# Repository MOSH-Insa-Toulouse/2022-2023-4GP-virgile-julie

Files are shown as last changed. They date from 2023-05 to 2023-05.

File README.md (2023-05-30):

# 2022-2023-4GP-virgile-julie
Projet 4GP du capteur au banc de test en open source hardware
---
## Sommaire
  - [1) Livrables](#1-livrables)
  - [2) Description](#2-description)
  - [3) Shield PCB](#3-shield-pcb)
  - [4) Arduino](#4-arduino)
  - [5) Application Android APK](#5-application-android-apk)
  - [6) Banc de test et mesures](#6-banc-de-test-et-mesures)
  - [7) Datasheet](#7-datasheet)
  - [8) Limites et perspectives](#8-Limites-et-perspectives)
---
## 1) Livrables

Lors de notre projecteur, nous avons décidé de réaliser l'ensemble des options (headers) sur la schématique du shield: 
- capteur
- module bluetooth
- flex sensor
- écran OLED
- potentiomètre digital
 
 Pour se faire, nous avons du réaliser un cahier des charges adaptés:
 
-  Réalisation d'un Shield PCB sur KiCad
-  Réalisation d'un code Arduino permettant la mesure du capteur, ainsi que le réglage du potentiomètre, l'affichage sur un écran OLED, l'envoie des données par module Bluetooth
- Réalisation d'une Application android APK réalisée avec MIT APP INVENTOR
- Réalisation d'une Datasheet du capteur
---
## 2) Description

Dans ce projet, nous allons concevoir un capteur résistif fonctionnant sur la base d'un phénomène physique observé qui est l'effet tunnel. En faisant varier la distance séparant les particules du réseau( par des déformations en compression et en tension), la conductivité du graphite varie ainsi que sa résistivité.

Pour appliquer ce phènomène, la jauge de contrainte sera peu couteuse. Elle se présente sous la forme d’un U en papier, sur lequel on vient déposer du graphite à l’aide d’un crayon à papier ceci est très simple à réaliser et sa fabrication ne génère pas d’impact négatif sur l’environnement. A noter aussi que la réponse du capteur va dépendre du type de mine utilisée. 

Nous avons débuté notre projet par la fabrication de notre shield pour notre chaine de mesures. Ce dernier a été conçu a l'aide du logiciel KICAD  sur la base du amplificateur transimpédance simulation électrique du circuit associé au shield sur le logiciel LTSpice.

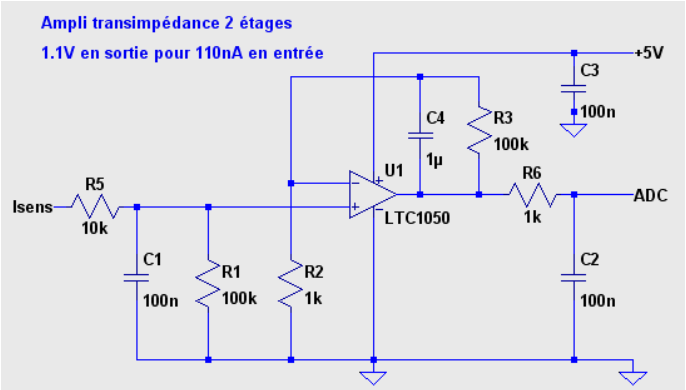
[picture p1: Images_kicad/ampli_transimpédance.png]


Pour exploiter le signal de sortie du capteur par un convertisseur analogique-numérique d’une carte Arduino, la sortie du capteur est reliée à un circuit amplificateur transimpédance. Ce circuit dispose de trois étages de filtrage : 
- Un filtre passe-bas R1C1 qui permet de filtrer les bruits en courants sur le signal d’entrée
- Un filtre passe bas R3C4 couplé à un amplificateur opérationnel LTC1050 permettant de filtrer la composante du bruit à 50 Hz provenant du réseau électrique
- Un filtre de sortie R5C2 qui coupe les bruits due à l’échantillonnage de l’ADC
On retrouve la valeur de résistance du capteur grâce à la formule suivante : 
R=(1+R3/R2)*R1*Vcc/Vadc-R1-R5

Par la suite, nous avons ensuite imprimé notre circuit PCB après validation de celle-ci, qui aura demande de multiples essais. 
Puis, nous avons réalisé le montage des composants sur la carte vierge avec le matériel ci-dessous.

Matériel nécessaire
* 1 carte Arduino Uno
* 2 Résistance de 100kΩ
* 1 Résistance de 1kΩ
* 1 Potentiomètre digital MCP-41050
* 2 Condensateurs 100nF
* 1 Condensateurs 1µF
* 1 AOP LTC1050
* 1 Écran OLED01
* 1 Module Bluetooth HC-05

Puis, nous avons codé avec l'usage d'une carte Arduino le code permettant la lecture des mesures du capteur ainsi que l'ajout sur le code des fonctions associés aux différentes options ajoutés soit l'écran OLED, le module Bluetooth et le potentiomètre digital.  
Ensuite, nous avons développé une application Android qui a pour but de recevoir des données via Bluetooth grâce le site MIT App Inventor.  
Et enfin, nous avons réalisé notre propre banc de test : nous avons effectué un test de rayon de courbure et un test de répétabilité avec deux types de crayons (2B, HB2).  

---
## 3) Shield PCB

### Réalisation de la Schématique de Shield
Cette partie se consacre à la réalisation et la fabrication du support éléctronique, soit le PCB de notre projet. Il a été réalisé sur le logiciel Kicad en se basant sur le template d'un arduino uno.

Pour se faire, nous avons conçu l'ensemble des symboles et empreintes associés aux options choisis précédements. Avec les empreintes, nous les avons connecté avec le reste du circuit existant afin d'obtenir notre shield.

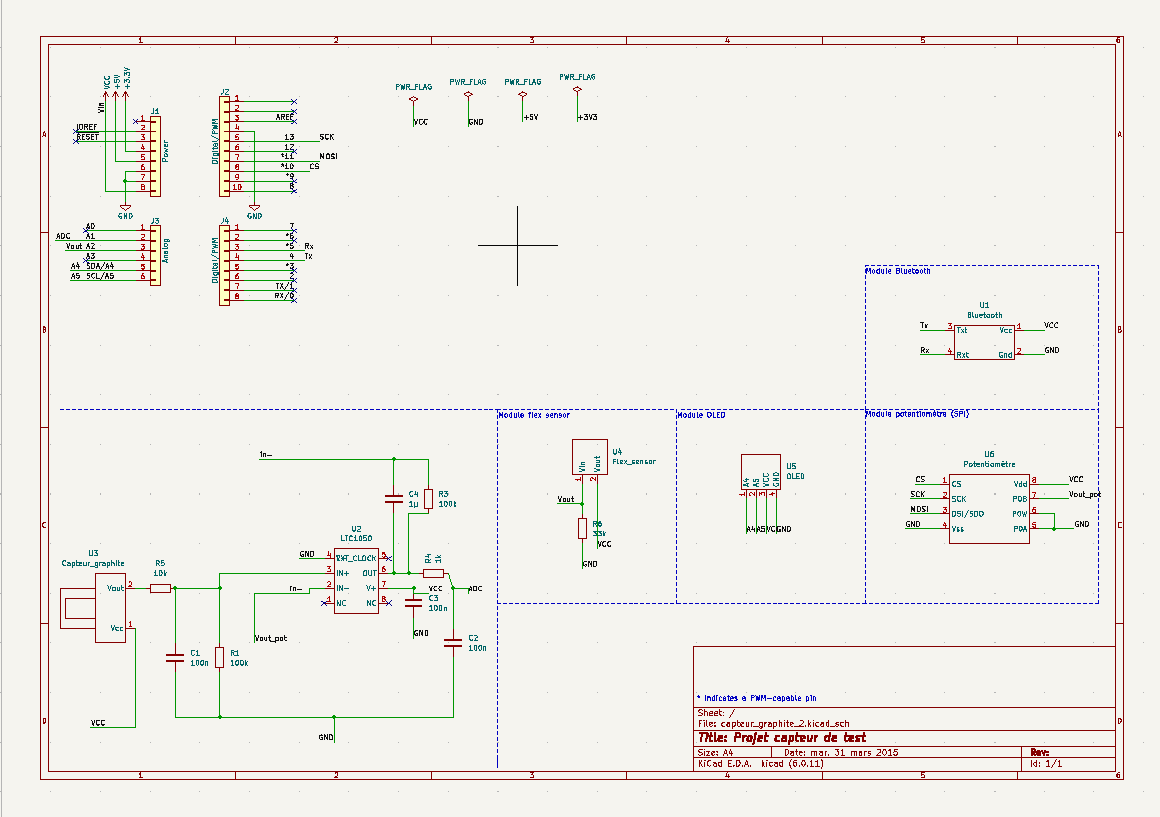
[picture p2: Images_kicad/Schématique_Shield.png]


### Réalisation de la Schématique du PCB
En se basant sur notre Shield, nous avons réalisé le routage de notre circuit en prenant soin de limiter les distances entre les composantes et leur pins associés. Cette étape fut très laboriseuse car le fait d'avoir une seule couche pour le PCB, nous obligeait de trouver des stratagèmes d'optimisation de place et de placement. Lorsque cette étape était fini, nous pouvons passer à la pose du plan de masse de notre circuit.

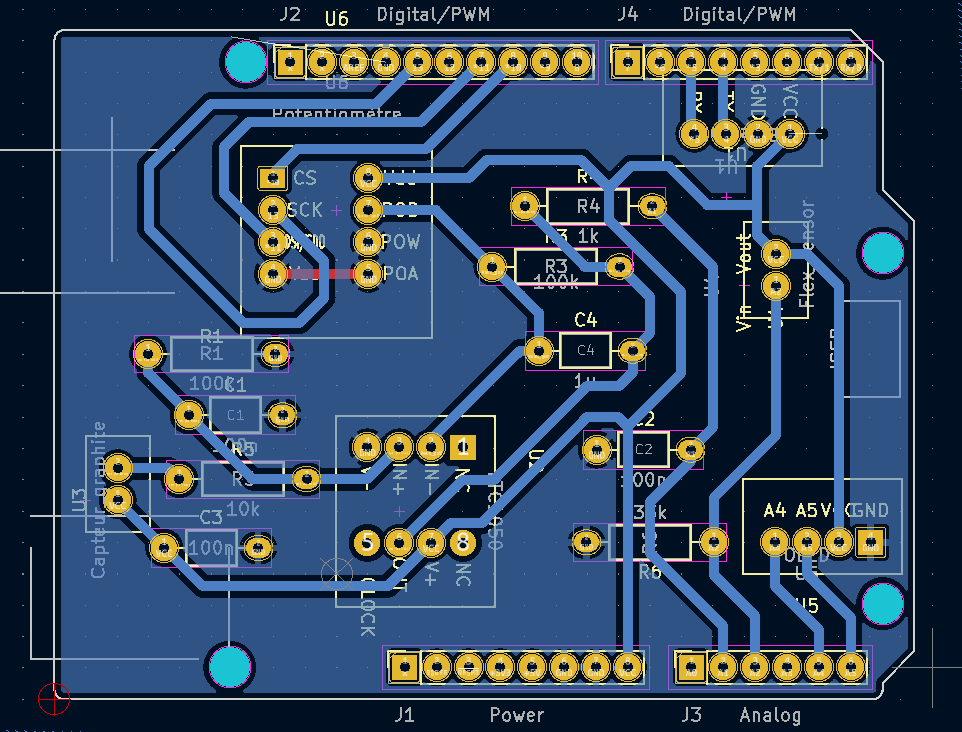
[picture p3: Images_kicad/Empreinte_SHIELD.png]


Comme nous pouvons le voir, le résultant possède néanmoins un fil supplémentaire, un fil rouge, qui sera ajouté lors de la fabrication du shield pour respecter le plan de masse. 

### Fabrication du PCB
Le PCB a été fabriqué à partir d'une plaquette d’époxy recouverte d’une fine couche de cuivre. 

Etapes de fabrication:

* Réaliser une insolation aux UVs de notre plaquette avec le calque de notre circuit (10 minutes)
* Retirer la partie de résine non isolée avec un révélateur
* Plonger notre plaquette dans un bain de percholorure de fer

### Assemblage des composantes
Lorsque le PCB a été fabriqué, il nous reste l'étape d'assemblage du shield. Pour se faire, il nous faut donc percer le PCB et souder les composants.
Pour ce qui est du perçage, dans les consignes, il était dit de prévoir deux tailles de trous sur le Kicad, soit un de diamètre 0,8mm pour les composants et headers et un de diamètre 1mm pour les broches de connexion de la carte Arduino Uno.

## 4) Arduino

## 5) Application Android APK
Nous avons développé une application android à l’aide du développeur MIT App Inventor. Couplée au module Bluetooth HC-05, cette application permet d’afficher en direct la résistance du capteur et l’évolution de la résistance en fonction du temps grâce à  un graphique déroulant.

appli_bluetooth

Voici le schéma block de notre application : 

schéma_block_appli_1

schéma_block_appli_2

Le graphique déroulant permet une analyse qualitative plus que quantitative car le graphique déroulant n’a pas d’échelle en ordonnée. 
Les limites de cette application sont : 
-	Si on lance l’application alors que la carte Arduino tournait déjà, il y a une erreur car l’application ne reçoit pas une seule valeur numérique mais plusieurs
-	Si l’application reçoit la valeur infinie, l’application affiche une erreur 

## 6) Banc de test et mesures 

Un banc de test présentant différents arcs de cercle de différents diamètres a été utilisé pour les mesures de caractéristiques électriques. Le but est de mesurer la variation de résistance entre le capteur « à plat » et le capteur courbé sur les arcs de cercle. 
En désignant r le rayon du cercle et e l’épaisseur du banc de test, on calcule la déformation de chaque arc de cercle à partir de cette formule : ε = e / 2r 

bancdetest

Nous avons testé notre capteur avec deux crayons différents : un avec une mine 2B et un avec une mine HB2.

graph_mine2B

Caractéristique du capteur en tension en fonction d’un pourcentage de déformation pour un crayon 2B

grpah_mineHB2

Caractéristique du capteur en tension en fonction d’un pourcentage de déformation pour un crayon HB2

## 7) Datasheet

Vous trouverez le lien vers la datasheet du capteur : 

## 8) Limites et perspectives

La réponse du capteur dépend grandement de la quantité déposée de graphite, ce qui est difficilement mesurable dans le cas du dépot avec une mine de crayon. 

La valeur de la résistance du potentiomète est modifiable seulement au niveau du code : si on veut modifier sa valaeur, il faut modifier le code. On peut imaginer un dispositif qui permet de modifier sa valeur grâce à l'ajout d'un composant au niveau du Hardware, comme par exemple un encodeur rotatif.

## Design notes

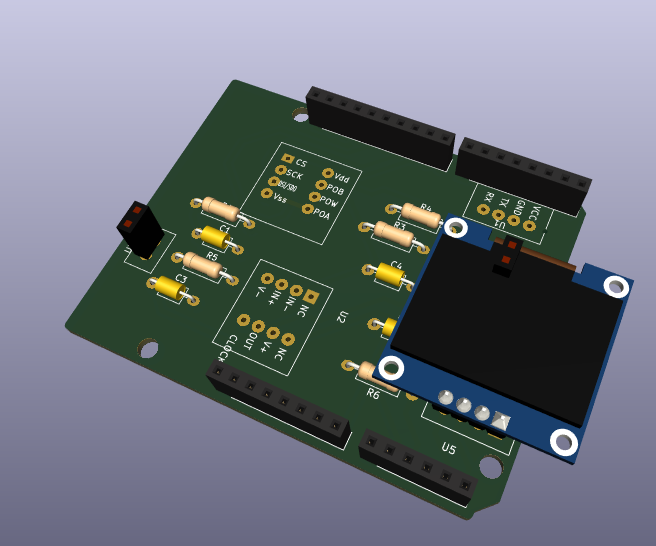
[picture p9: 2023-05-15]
Images_kicad/3D_vue_empreinte_shield.png

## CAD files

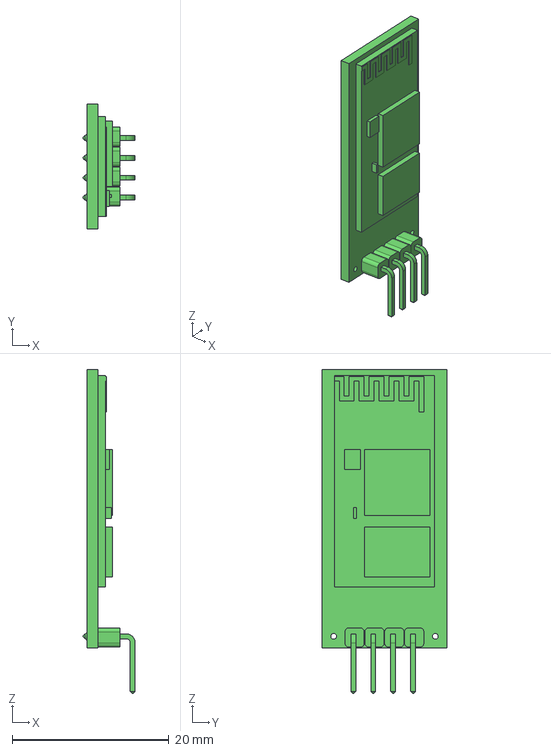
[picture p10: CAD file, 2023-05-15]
kicad/projet_final_kicad/Composant 3D/HC-05 Bluetooth Module.stp
6.68 x 16.0 x 41.4 mm

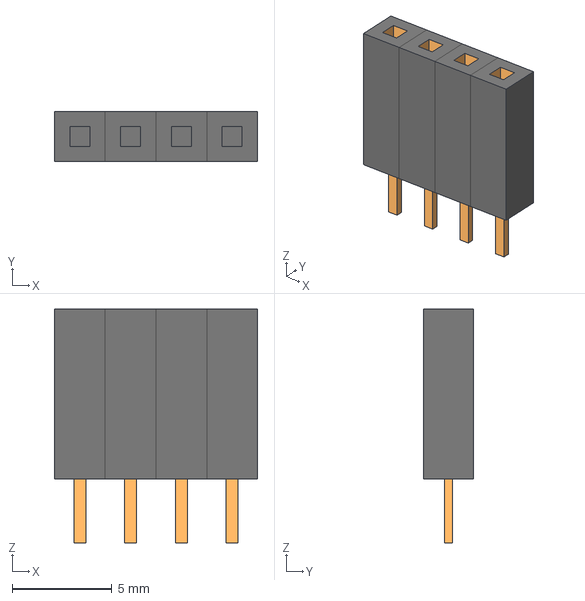
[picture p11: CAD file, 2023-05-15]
kicad/projet_final_kicad/Composant 3D/header/FH01-04SS.stp
10.2 x 2.50 x 11.7 mm

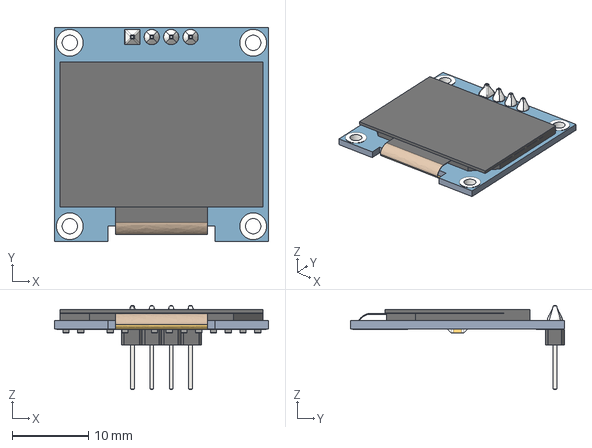
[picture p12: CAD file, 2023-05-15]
kicad/projet_final_kicad/Composant 3D/0.96 OLED v3.step
28.0 x 28.0 x 11.0 mm

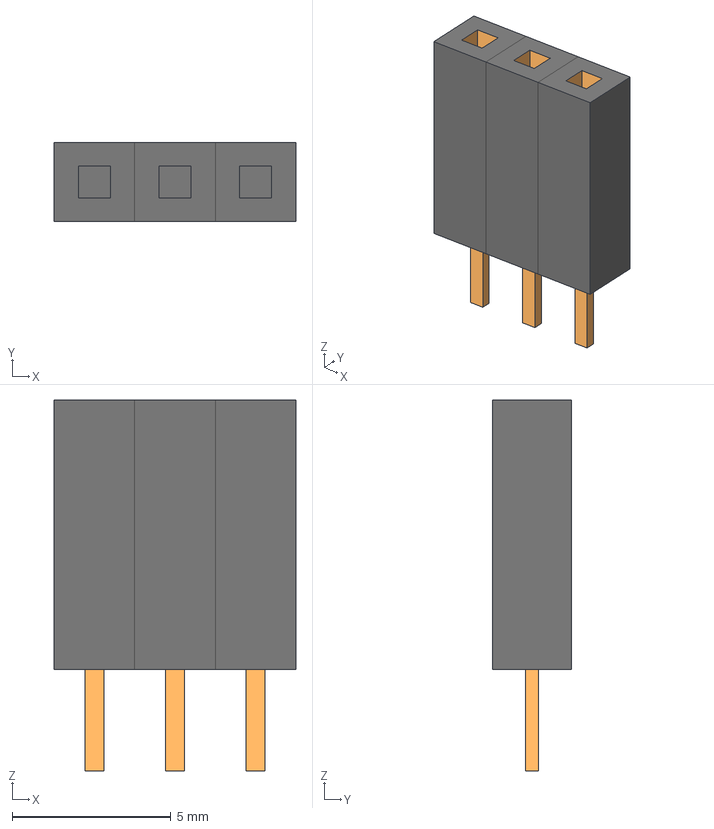
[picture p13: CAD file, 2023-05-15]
kicad/projet_final_kicad/Composant 3D/header/FH01-03SS.stp
7.62 x 2.50 x 11.7 mm

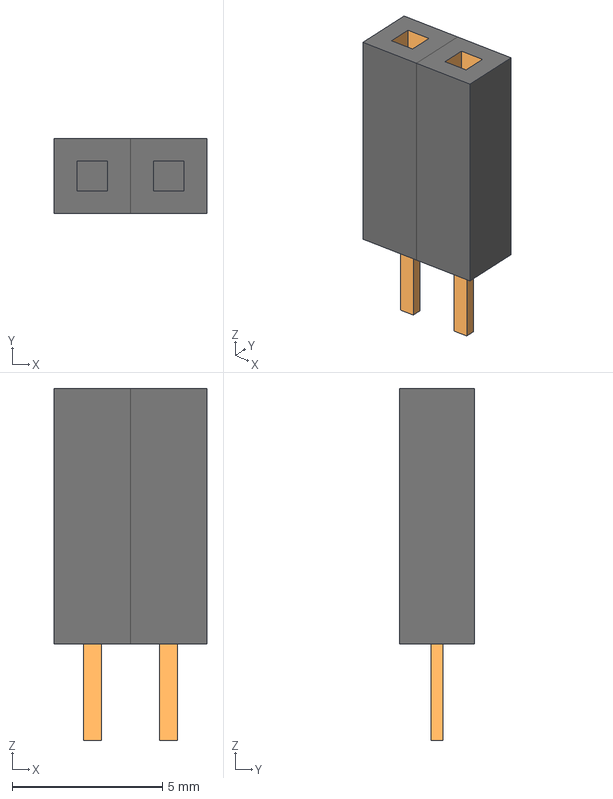
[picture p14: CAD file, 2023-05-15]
kicad/projet_final_kicad/Composant 3D/header/FH01-02SS.stp
5.08 x 2.50 x 11.7 mm
Cnt1 x 2
Cnt2 x 2

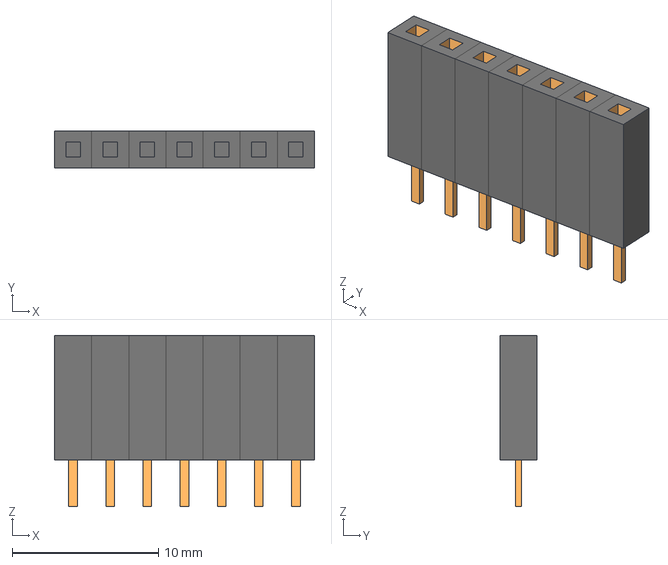
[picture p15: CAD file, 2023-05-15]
kicad/projet_final_kicad/Composant 3D/header/FH01-07SS.stp
17.8 x 2.50 x 11.7 mm

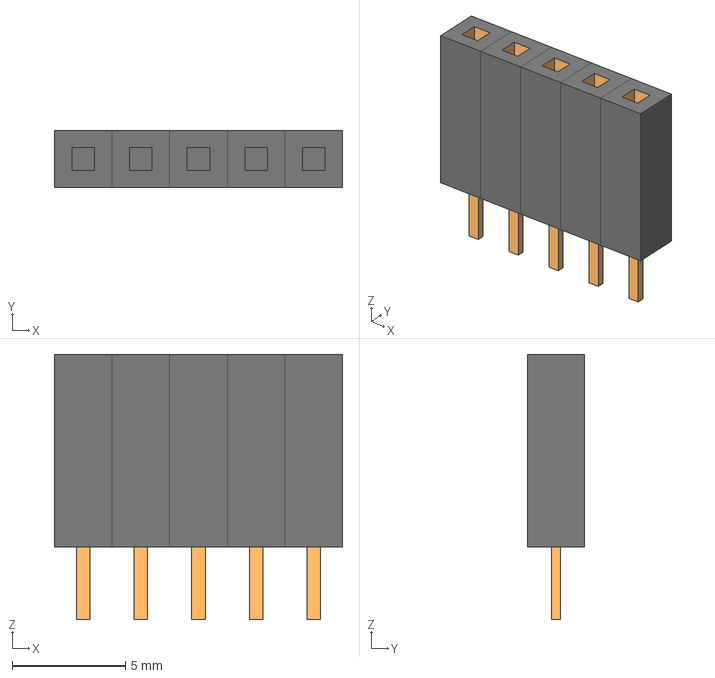
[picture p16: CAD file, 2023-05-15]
kicad/projet_final_kicad/Composant 3D/header/FH01-05SS.stp
12.7 x 2.50 x 11.7 mm

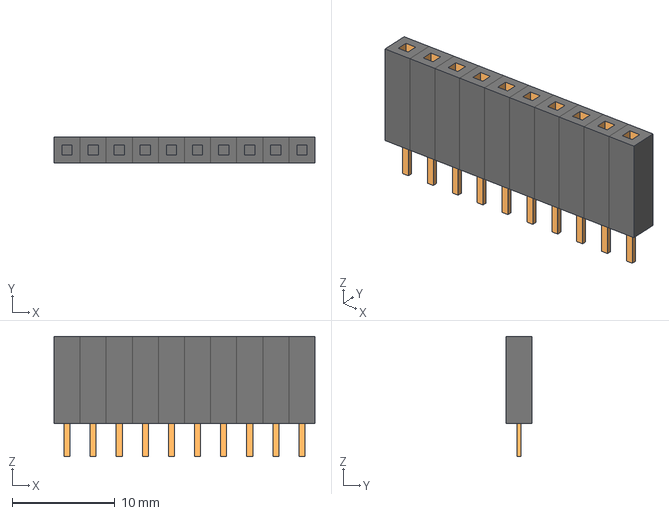
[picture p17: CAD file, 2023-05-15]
kicad/projet_final_kicad/Composant 3D/header/FH01-10SS.stp
25.4 x 2.50 x 11.7 mm

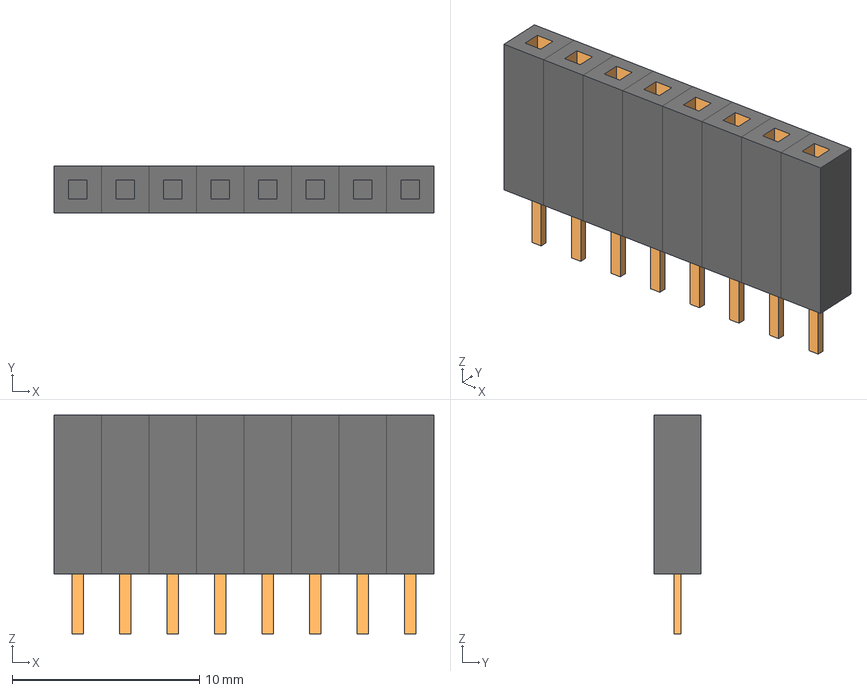
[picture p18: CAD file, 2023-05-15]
kicad/projet_final_kicad/Composant 3D/header/FH01-08SS.stp
20.3 x 2.50 x 11.7 mm

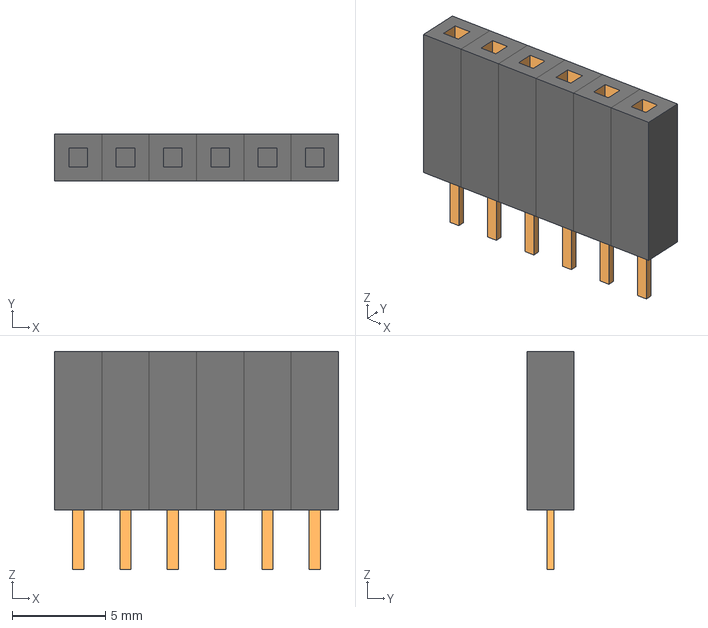
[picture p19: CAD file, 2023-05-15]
kicad/projet_final_kicad/Composant 3D/header/FH01-06SS.stp
15.2 x 2.50 x 11.7 mm

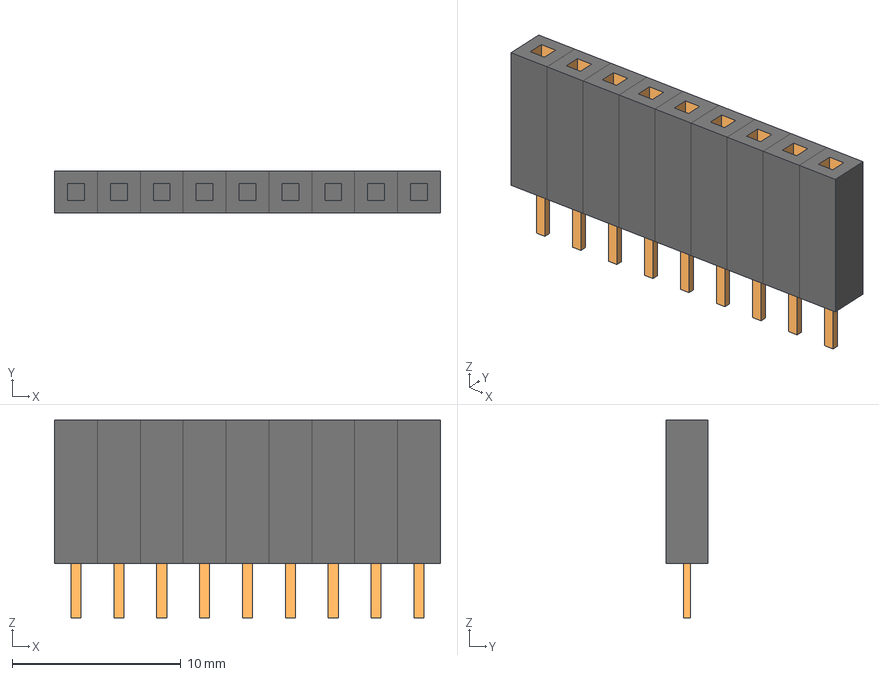
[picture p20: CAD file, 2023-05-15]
kicad/projet_final_kicad/Composant 3D/header/FH01-09SS.stp
22.9 x 2.50 x 11.7 mm

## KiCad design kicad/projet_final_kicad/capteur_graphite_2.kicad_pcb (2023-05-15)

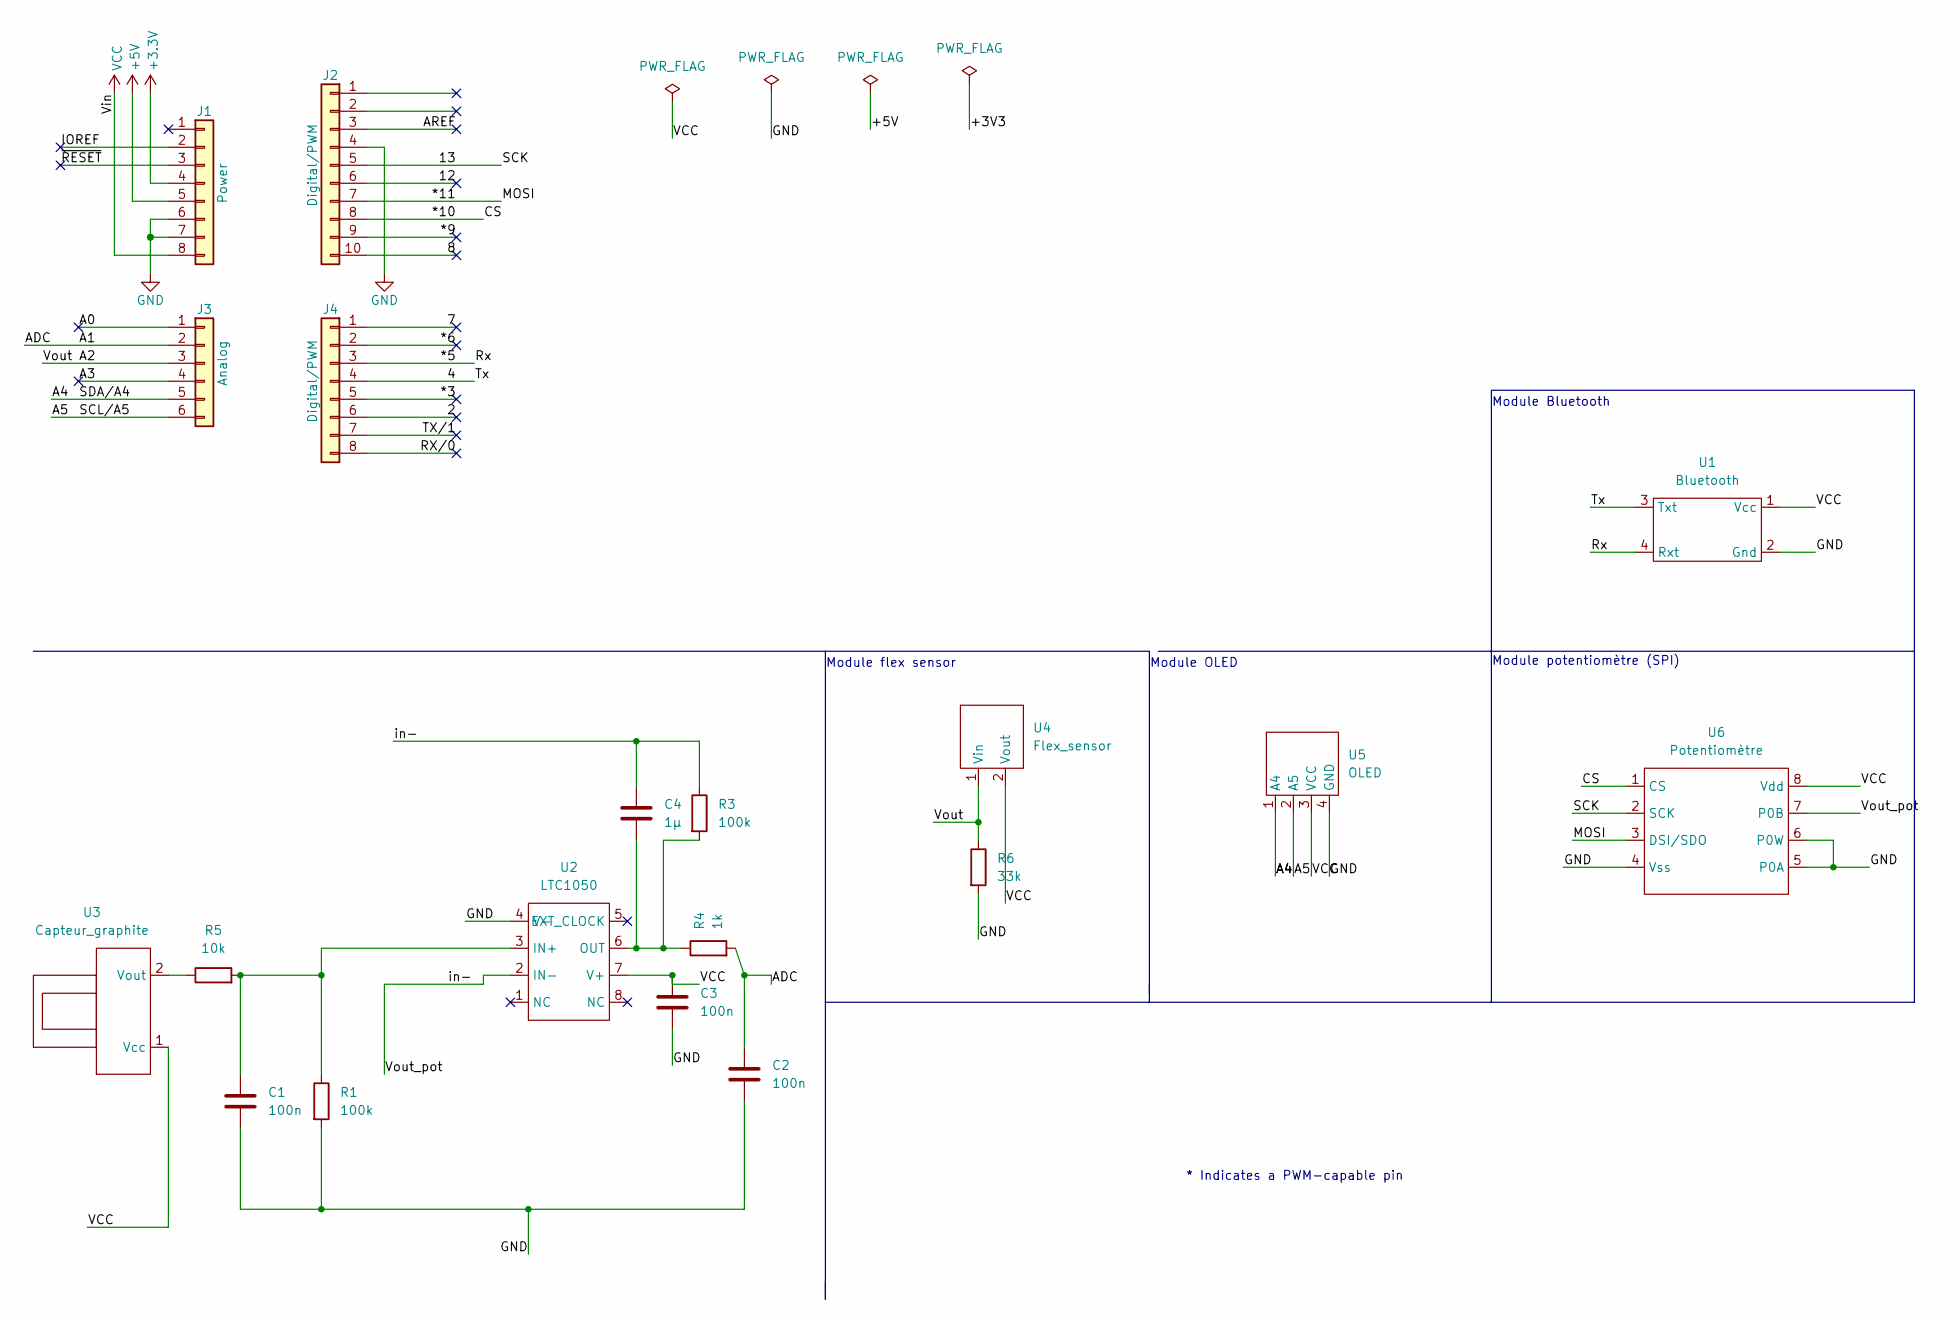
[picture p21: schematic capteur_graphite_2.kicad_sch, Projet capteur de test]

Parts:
C1, C2, C3: 100n; C_Axial_L3.8mm_D2.6mm_P7.50mm_Horizontal
C4: 1µ; C_Axial_L3.8mm_D2.6mm_P7.50mm_Horizontal
J1: Power; PinSocket_1x08_P2.54mm_Vertical
J2: Digital/PWM; PinSocket_1x10_P2.54mm_Vertical
J3: Analog; PinSocket_1x06_P2.54mm_Vertical
J4: Digital/PWM; PinSocket_1x08_P2.54mm_Vertical
R1, R3: 100k; R_Axial_DIN0207_L6.3mm_D2.5mm_P10.16mm_Horizontal
R4: 1k; R_Axial_DIN0207_L6.3mm_D2.5mm_P10.16mm_Horizontal
R5: 10k; R_Axial_DIN0207_L6.3mm_D2.5mm_P10.16mm_Horizontal
R6: 33k; R_Axial_DIN0207_L6.3mm_D2.5mm_P10.16mm_Horizontal
U1: Bluetooth
U2: LTC1050; LTC
U3: Capteur_graphite
U4: Flex_sensor; Flex sensor
U5: OLED
U6: Potentiomètre; Pot

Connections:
+3V3: J1.4
+5V: J1.5
/2: J4.6
/4: J4.4, U1.3 (Txt)
/7: J4.1
/8: J2.10
/12: J2.6
/13: J2.5, U6.2 (SCK)
/*3: J4.5
/*5: J4.3, U1.4 (Rxt)
/*6: J4.2
/*9: J2.9
/*10: J2.8, U6.1 (CS)
/*11: J2.7, U6.3 (DSI/SDO)
/A0: J3.1
/A1: C2.2, J3.2, R4.2
/A2: J3.3, R6.1, U4.1 (Vin)
/A3: J3.4
/A4: J3.5, U5.1 (A4)
/A5: J3.6, U5.2 (A5)
/AREF: J2.3
/IOREF: J1.2
/RX/0: J4.8
/TX/1: J4.7
/Vout_pot: C4.1, R3.1, U2.2 (IN-), U6.7 (P0B)
/~RESET: J1.3
GND: C1.2, C2.1, C3.2, J1.6, J1.7, J2.4, R1.2, R6.2, U1.2 (Gnd), U2.4 (NC), U5.4 (GND), U6.4 (Vss), U6.5 (P0A), U6.6 (P0W)
unnamed: C1.1, R1.1, R5.2, U2.3 (IN+)
unnamed: C4.2, R3.2, R4.1, U2.6 (V+)
unnamed: R5.1, U3.2 (Vout)
VCC: C3.1, J1.8, U1.1 (Vcc), U2.7 (OUT), U3.1 (Vcc), U4.2 (Vout), U5.3 (VCC), U6.8 (Vdd)

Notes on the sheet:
Module OLED
Module flex sensor
Module potentiomètre (SPI)
Module Bluetooth
* Indicates a PWM-capable pin

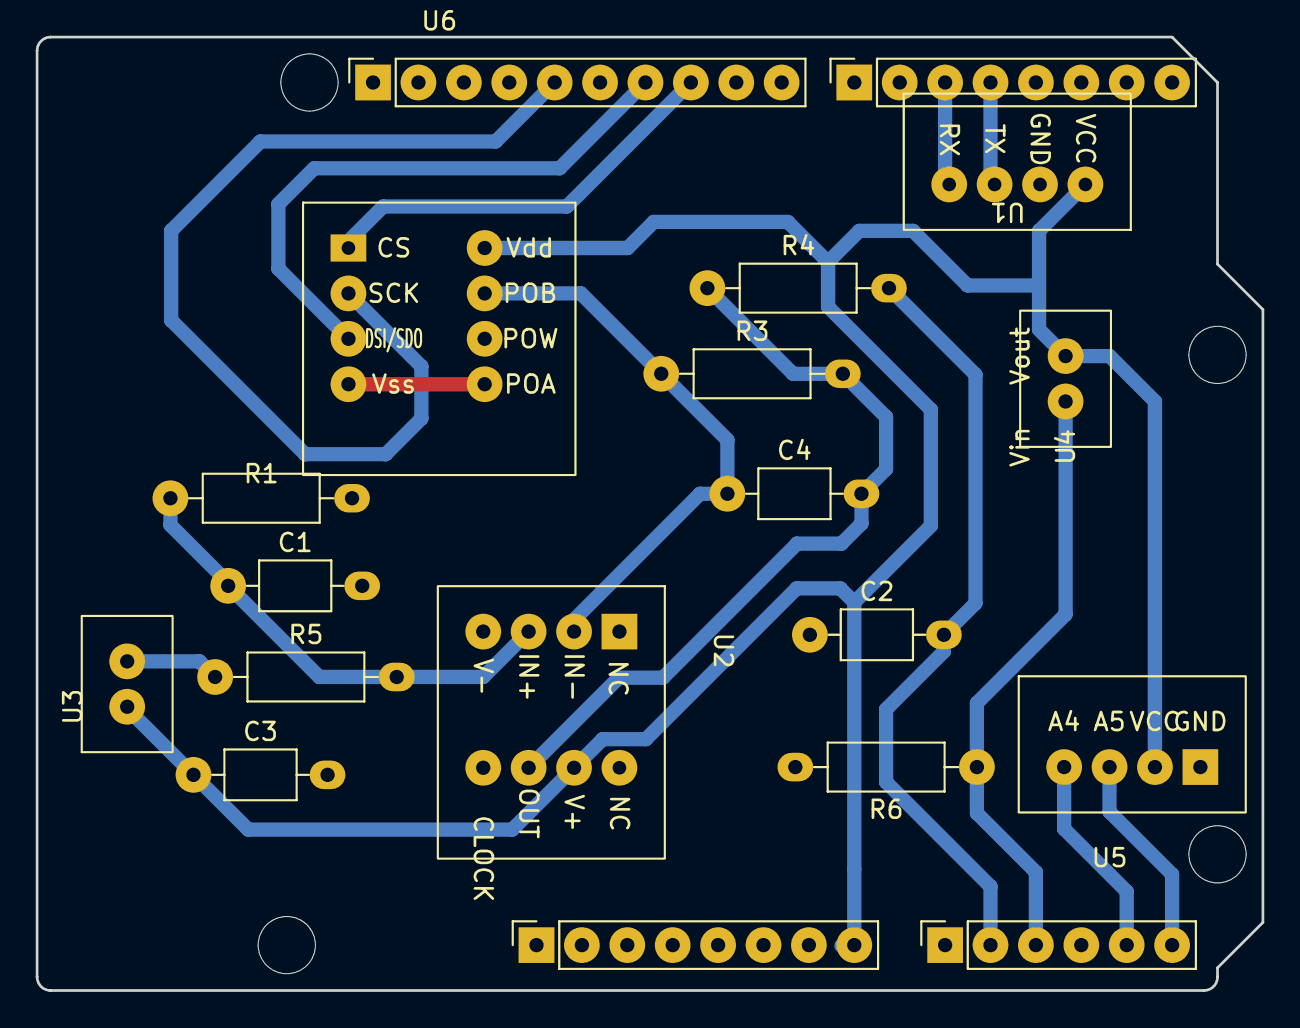
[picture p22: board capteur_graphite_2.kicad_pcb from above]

Board: 2 copper layers, 68.6 x 53.3 mm, 23 parts (0 on the bottom side), 15 nets.

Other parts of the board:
MH1, MH2, MH3, MH4: MountingHole_3.2mm

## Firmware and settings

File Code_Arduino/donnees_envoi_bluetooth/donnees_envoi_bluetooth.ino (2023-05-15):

#include <SoftwareSerial.h>
#include <Wire.h>
#include <Adafruit_SSD1306.h>
# define nombreDePixelsEnlargeur 128
# define nombreDePixelsEnHauteur 64
#define  brocheResetOLED -1 
# define adresseI2CecranOLED 0x3C

int dataPin = A1;
SoftwareSerial mySerial (6, 7);
int consigne=0;
//int16_t posx = 40;
//int16_t posy = 10;
int16_t couleur = SSD1306_WHITE;
Adafruit_SSD1306 ecranOLED(nombreDePixelsEnlargeur, nombreDePixelsEnHauteur, &Wire, brocheResetOLED);



void setup() {
  Serial.begin(9600);
if(!ecranOLED.begin(SSD1306_SWITCHCAPVCC,adresseI2CecranOLED))
  while(1); 
  //Serial.println("ok");
  ecranOLED.clearDisplay();
  ecranOLED.setTextSize(2);
  delay(2000);
  ecranOLED.setCursor(64,32);
  ecranOLED.setTextColor(SSD1306_WHITE);
  
 
   
  
}

void loop() {
  float mesure = analogRead(dataPin);  //recup valeur capteur 
  Serial.println(mesure); //retoune la valeur 
  delay(1);
  //Serial.println(Serial.read());
//Serial.println(mySerial.available());
 while (mySerial.available()>0){
   consigne=mySerial.read();
      Serial.println(consigne,DEC);
      if (consigne==1){
        digitalWrite(13,HIGH);
      }
      if (consigne==2){
        digitalWrite(13,LOW);
      }
  }
  
      ecranOLED.clearDisplay();
      // calcul
      mesure=(5/1023)*mesure;
      float resistance = ((1+(100))*100000*(5/mesure)-100000-10000);// changer capteur trop nulle l'autre
      
      ecranOLED.println(resistance);
      //Serial.print("lz");
      ecranOLED.display();
       ecranOLED.setCursor(64,32);
      delay(2000);
}

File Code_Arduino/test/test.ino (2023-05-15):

#include <SoftwareSerial.h>
#include <Wire.h>

#define rxPin 5 //Broche 5 en tant que RX, a raccorder sur TX du HC-05
#define txPin 4 //Broche 4 en tant que TX, a raccorder sur RX du HC-05 
#define baudrate 9600 //bluetooth 
SoftwareSerial mySerial(rxPin ,txPin); //D�finition du software serial pour bluetooth 

#include <Adafruit_SSD1306.h>    //init OLEd 
# define nombreDePixelsEnlargeur 128    //init OLEd
# define nombreDePixelsEnHauteur 64    //init OLEd
#define  brocheResetOLED -1   //init OLEd
# define adresseI2CecranOLED 0x3C   //init OLEd

//const for flex sensor
const float VCC = 5;      // voltage at Ardunio 5V line
const float R_DIV = 33000.0;  // resistor used to create a voltage divider
const float flatResistance = 25000.0; // resistance when flat
const float bendResistance = 100000.0;  // resistance at 90 deg

int dataPin = A1;  //pin input du signal de sortie du capteur graphite 
int dataPinF = A2;      //pin input du signal de sortie du Flex Sensor 

//SoftwareSerial mySerial (6, 7);
int consigne=0; //bluetooth 
int16_t couleur = SSD1306_WHITE;// init OLED
Adafruit_SSD1306 ecranOLED(nombreDePixelsEnlargeur, nombreDePixelsEnHauteur, &Wire, brocheResetOLED); // init OLED

// Déclaration Digital pot
#include <SPI.h>

const byte csPin           = 10;      // MCP42100 chip select pin
const int  maxPositions    = 256;     // wiper can move from 0 to 255 = 256 positions
const long rAB             = 46000;   // 50k pot resistance between terminals A and B, 
                                      
const byte rWiper          = 125;     // 125 ohms pot wiper resistance
const byte pot0            = 0x11;    // pot0 addr // B 0001 0001
const byte pot0Shutdown    = 0x21;    // pot0 shutdown // B 0010 0001

void setPotWiper(int addr, int pos) {
  pos = constrain(pos, 0, 255);            // limit wiper setting to range of 0 to 255
  digitalWrite(csPin, LOW);                // select chip
  SPI.transfer(addr);                      // configure target pot with wiper position
  SPI.transfer(pos);
  digitalWrite(csPin, HIGH);               // de-select chip

  // print pot resistance between wiper and B terminal
  long resistanceWB = ((rAB * pos) / maxPositions ) + rWiper;
  Serial.print("Wiper position: ");
  Serial.print(pos);
  Serial.print(" Resistance wiper to B terminal: ");
  Serial.print(resistanceWB);
  Serial.println(" ohms");
}



void setup() {
  Serial.begin(9600);

 // Init Bluetooth
  pinMode(rxPin,INPUT);
  pinMode(txPin,OUTPUT);
    
  mySerial.begin(baudrate);
  Serial.begin(baudrate);

  // Init ecran OLED 
  if(!ecranOLED.begin(SSD1306_SWITCHCAPVCC,adresseI2CecranOLED))
  while(1);   // Arrêt du programme (boucle infinie) si échec d'initialisation

  
  //Serial.println("ok");
  ecranOLED.clearDisplay();
  ecranOLED.setTextSize(2);
  delay(2000);
  ecranOLED.setCursor(0,0);
  ecranOLED.setTextColor(SSD1306_WHITE);
  
 // Digital pot 
  Serial.println("MCP41100 Demo");
  digitalWrite(csPin, HIGH);        // chip select default to de-selected
  pinMode(csPin, OUTPUT);           // configure chip select as output
  SPI.begin();   
  
  // mettre  le pot à la valeur souhaitée
  Serial.println("Pot 0 Control ");
  setPotWiper(pot0, 6); // réglage du pot à 2% de la R to (50k)
  delay(1000);

}
void loop() {


  //mesure capteur graphite 
  float mesure = analogRead(dataPin);  //recup valeur capteur 
  Serial.println("mesure capteur graphite ");
  Serial.println(mesure); //retoune la valeur en binaire de la tension 
  delay(1);
    
      // calcul
      mesure=(4.2/1023)*mesure;
      float resistance = ((1+(100))*100000*(VCC/mesure)-100000-10000);// changer capteur trop nulle l'autre
      Serial.println("R=");
      Serial.println(resistance); //retoune la valeur de résistance du capteur graphite 

      


      
  //mesure flex sensor
  float ADCflex = analogRead(dataPinF);  //recup valeur Flex sensor 
  //Serial.println("mesure Flex sensor ");
  //Serial.println(mesure1); //retoune la valeur 
  float Vflex = ADCflex * VCC / 1023.0;
  float Rflex = R_DIV * (VCC / Vflex - 1.0);
  float angle = map(Rflex, flatResistance, bendResistance, 0, 90.0); //calcul angle
  int deformationFlex = (angle/180.0)*100; 
  //deformationFlex=(int)deformationFlex;
  //Serial.println("Bend: " + String(angle) + " degrees");
  //Serial.println();

  delay(500);
  delay(1);
  
  // Affichage ecran OLED
      ecranOLED.clearDisplay();
      ecranOLED.println("R(Mohm)=");
      ecranOLED.setCursor(0,16);
      ecranOLED.println(resistance/1000000); 
;     
      ecranOLED.setCursor(0,32);
      ecranOLED.println("def flex");
      ecranOLED.setCursor(0,48);
      ecranOLED.println(deformationFlex); 
      ecranOLED.setCursor(100,48);
      ecranOLED.println("%"); 
         
      //Serial.print("lz");
      ecranOLED.display();
      ecranOLED.setCursor(0,0);
      delay(2000);

    //Envoi Bluetooth
    mySerial.println(resistance/1000000); 
    delay (500); 
  
}

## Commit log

2023-05-15 Create Kicad
2023-05-15 ajouter datasheet docx
    [0.96 OLED v3.step, FH01-02SS.stp, FH01-03SS.stp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]
